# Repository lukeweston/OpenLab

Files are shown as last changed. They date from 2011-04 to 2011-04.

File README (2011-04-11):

Motherboard:

Because this board has a lot of hardware packed relatively tightly onto it, because it includes a few relatively exotic ICs which only exist as SMDs, and because of the size
restrictions of the Light version of Eagle, this board is designed almost entirely around surface-mount components.

Output Daughterboard:

This board contains the transistors for the open-collector transistor outputs (three of them), plus the amplifier and filter circuit for the analog waveform generator
output.

Because this board does not contain any particularly specialised ICs, and it does not require so many components packed on with such a high density, through-hole components
are used. Some people prefer through-hole components, and using through-hole components on this board means that it is more familar to construct for people who are not used
to working with surface mount components, and this means that this project includes both surface-mount components (on the motherboard), and through-hole components on this
daughterboard.

Pushbutton keypad board:

The pushbutton keypad is on its own separate small PCB. This makes it much easier to wire up the switches, compared to wiring up individual buttons manually.
This simple board includes the six pushbuttons and a string of resistors, and it is designed to be connected to a single analog input on the AVR and the button states
read by reading the analog voltage.

This is a very simple board which could easily be constructed by anyone, it is single sided, and the PCB is so simple that it could probably be fabricated at home.
It's probably quite valuable as a general pushbutton interface board for general Arduino activities outside the context of the ArduinoLab project, and this board probably
has wider appeal for these reasons.

I have written up the BOM for this board in a more verbose format, translating the Eagle-generated BOM into Digi-Key and element14 part numbers, so you can easily go shopping
for components. I have not yet been through this for the other boards.

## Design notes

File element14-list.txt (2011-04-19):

Element 14

(5+1) 6 x MCP73831 IC, SOT23-5 package				1332158		$1.44	
(5+1) 6 x LD1117S33 voltage regulator, SOT-223 package		1467779		$1.18
(5+1) 6 x 4053 IC, SOIC package					1014064		$0.847
(5x2+1) 11 x 4094 IC, SOIC package				1201297		$0.747

(5x3+2) 17 x MMBT2222 NPN transistor, SOT-23 package		1467896		$0.13
(5+1)    6 x FDS9431A P-channel MOSFET				1467989		$1.10
(5x6+2) 32 x green LED, SMD 0805				1686075		$0.158
(5x4+2) 22 x 5.6 V Zener diode, SOD-223				1757862		$0.06		

(5+1) 6 x 1 R, 1 W, SMD 2512 package				9235833		$0.097	
(5+1) 6 x 10 k SMD trimpot					46M2527		$0.134
(5x2) 10 x 10 k pot, standard panel-mounting 24 mm.		32M9482		$1.71

(5x10+5) 55 x 100 nF capacitor, SMD 0805			1759265		$0.018		
(5x2+2) 12 x 22 pF ceramic capacitor, SMD 0805			06R4053		$0.016

5 x 47 uF 10 V tantalum capacitor, SMD 'C' package		1754064		$0.795		
5 x 10 uF 10 V tantalum capacitor, SMD 'C' package		9753907		$0.832		
5 x 4700 uF 10 V electrolytic, through-hole, 5.08 mm pitch	9692754		$1.67

5 x 0.1" jumper shunt						1097975		$0.557		
(5x2) 10 x AA battery clips, PCB mounting.			908733		$6.09		
5 x 16 MHz crystal, HC-49S					1611734		$0.88	
(5+1) 6 x USB mini 'B' connector, SMD				1125348		$2.32		
5 x 2x3 pin header, for ICSP					1248132		$0.705		

(5x3) 15 x Green LED, through-hole, 3 mm			1461623		$0.14		
(5x3) 15 x 1N5819 diode, through-hole package			1017589		$0.173			
(5x3) 15 x 1N4004 diode, through-hole package			9109595		$0.034

5 x 1 nF ceramic capacitor, 0.1" lead pitch			1694095		$0.10		
(5x4) 20 x 100 nF ceramic capacitor, 0.1" lead pitch		1457658		$0.141

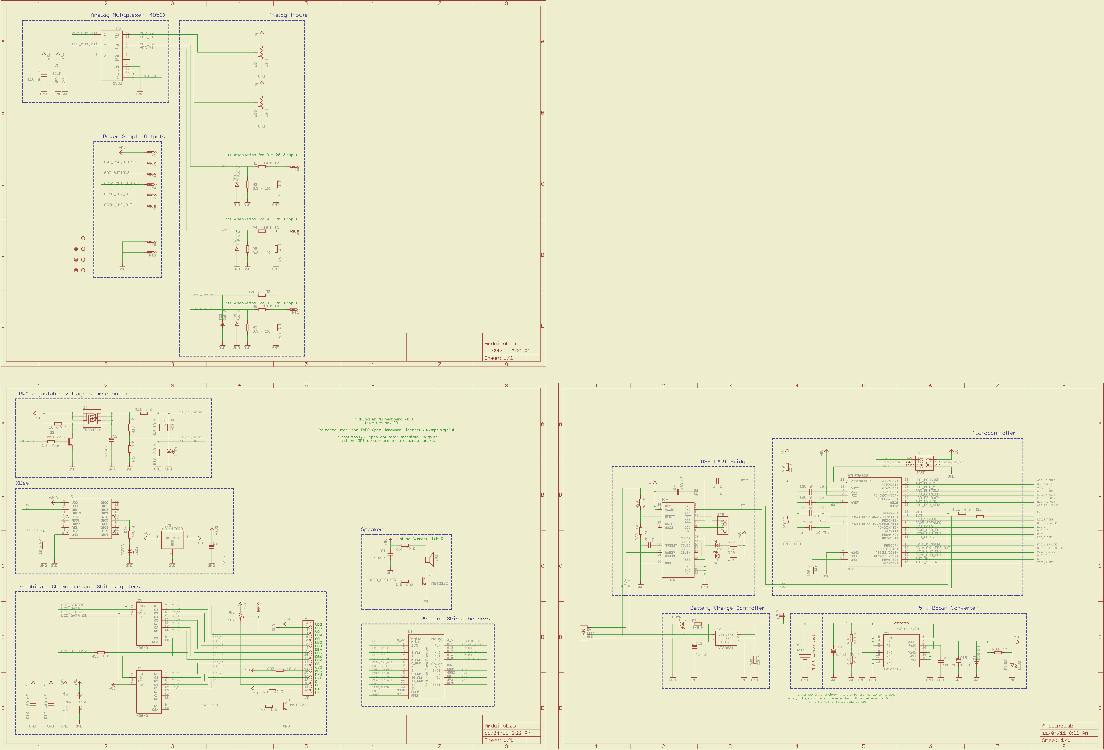
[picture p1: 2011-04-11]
motherboard/images/ArduinoLabMotherboardSchematic.png

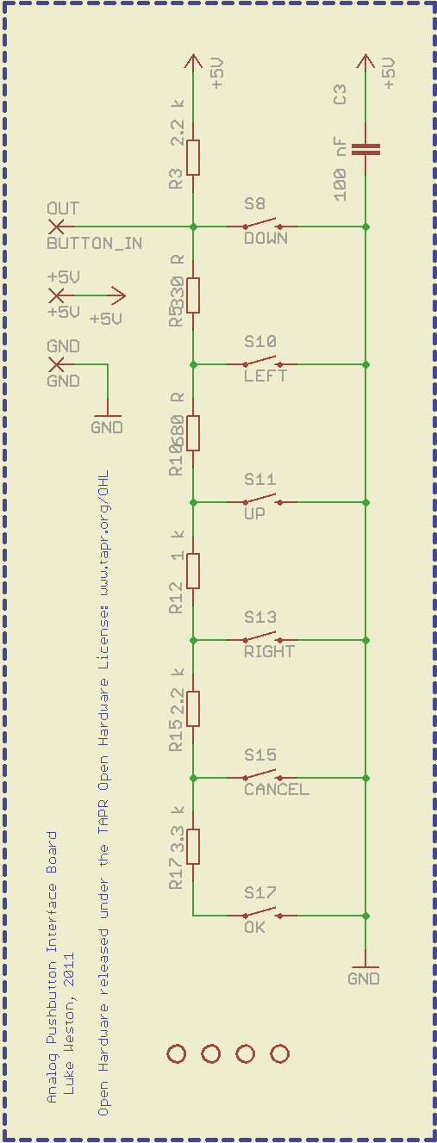
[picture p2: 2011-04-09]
buttons/images/PushbuttonsSchematic.png

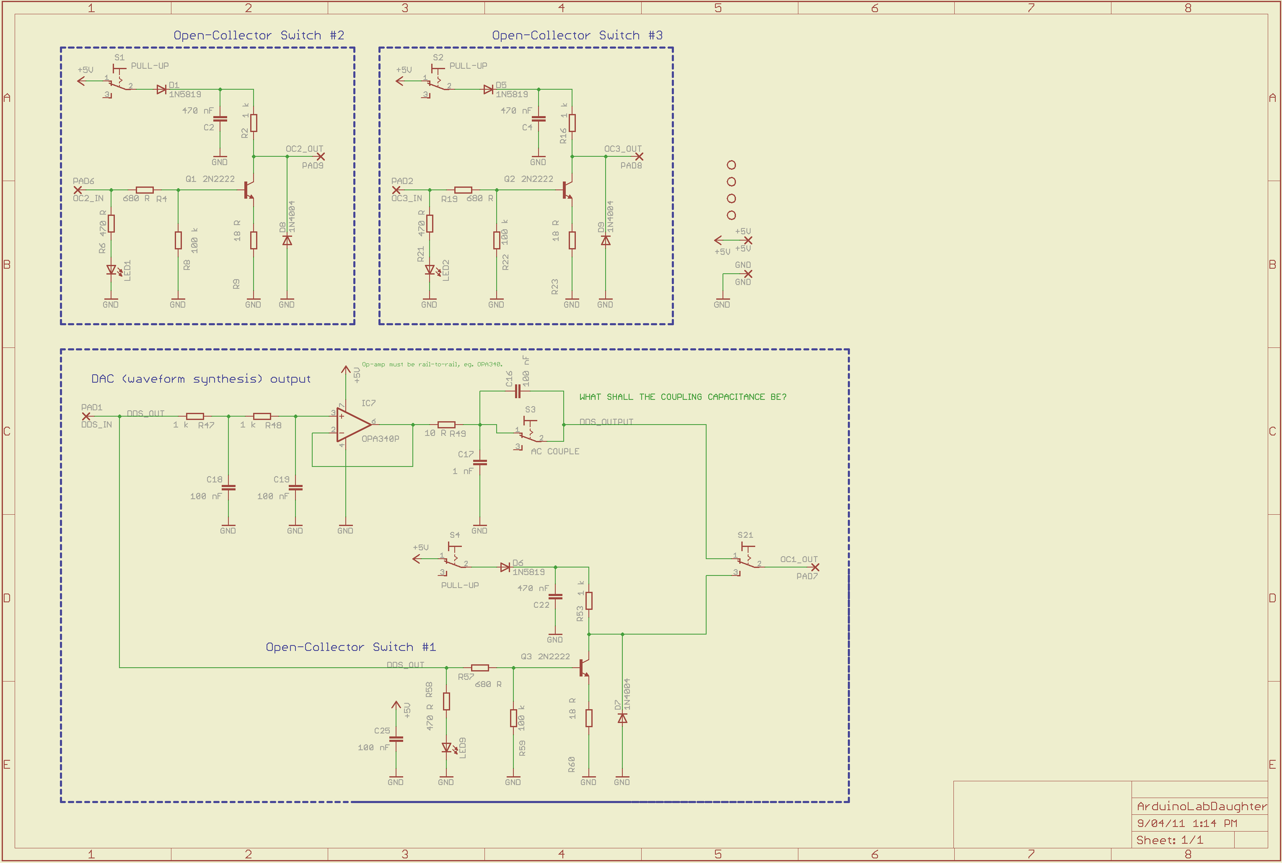
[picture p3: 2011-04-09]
daughterboard/images/ArduinoLabDaughterboardSchematic.png

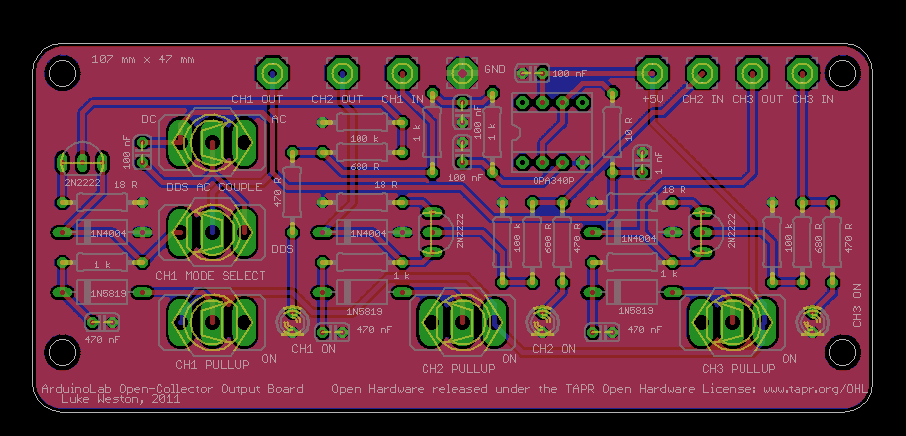
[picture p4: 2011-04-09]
daughterboard/images/ArduinoLabDaughterboardPCB.png

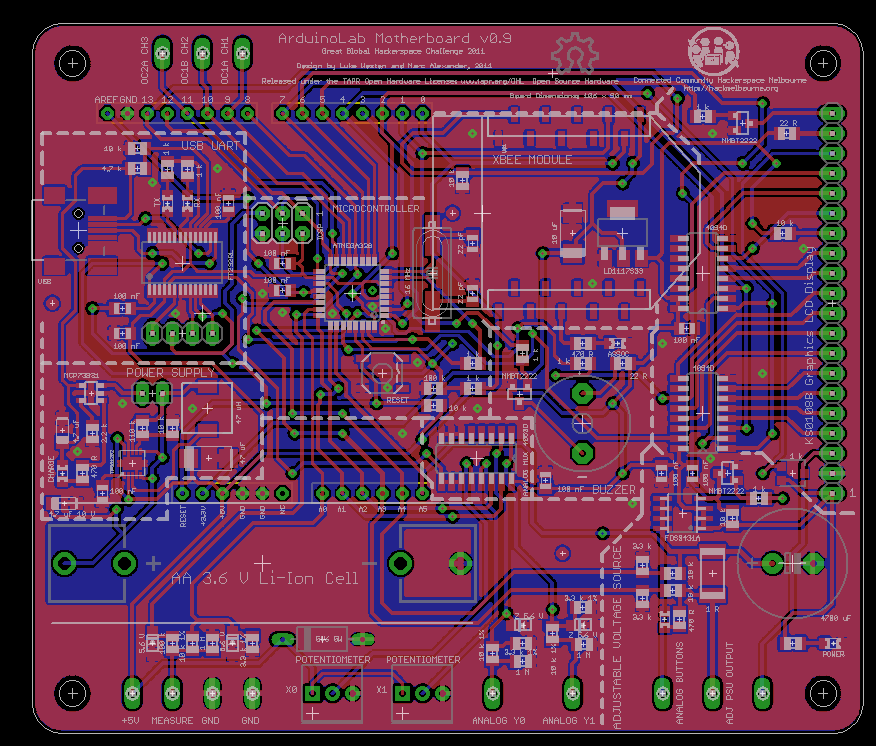
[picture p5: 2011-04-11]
motherboard/images/ArduinoLabMotherboardPCB.png

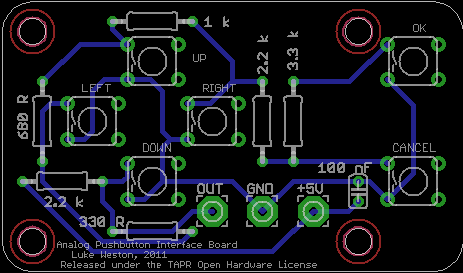
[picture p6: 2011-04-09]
buttons/images/PushbuttonPCB.png

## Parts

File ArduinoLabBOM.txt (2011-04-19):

Element 14
----------

Motherboards:
-------------
								
(5+1) 6 x MCP73831 IC, SOT23-5 package				1332158		$1.44	
(5+1) 6 x LD1117S33 voltage regulator, SOT-223 package		1467779		$1.18
(5+1) 6 x 4053 IC, SOIC package					1014064		$0.847
(5x2+1) 11 x 4094 IC, SOIC package				1201297		$0.747

(5x3+2) 17 x MMBT2222 NPN transistor, SOT-23 package		1467896		$0.13
(5+1)    6 x FDS9431A P-channel MOSFET				1467989		$1.10
(5x6+2) 32 x green LED, SMD 0805				1686075		$0.158
(5x4+2) 22 x 5.6 V Zener diode, SOD-223				1757862		$0.06		

(5+1) 6 x 1 R, 1 W, SMD 2512 package				9235833		$0.097	
(5+1) 6 x 10 k SMD trimpot					46M2527		$0.134
(5x2) 10 x 10 k pot, standard panel-mounting 24 mm.		32M9482		$1.71

(5x10+5) 55 x 100 nF capacitor, SMD 0805			1759265		$0.018		
(5x2+2) 12 x 22 pF ceramic capacitor, SMD 0805			06R4053		$0.016

5 x 47 uF 10 V tantalum capacitor, SMD 'C' package		1754064		$0.795		
5 x 10 uF 10 V tantalum capacitor, SMD 'C' package		9753907		$0.832		
5 x 4700 uF 10 V electrolytic, through-hole, 5.08 mm pitch	9692754		$1.67

5 x 0.1" jumper shunt						1097975		$0.557		
(5x2) 10 x AA battery clips, PCB mounting.			908733		$6.09		
5 x 16 MHz crystal, HC-49S					1611734		$0.88	
(5+1) 6 x USB mini 'B' connector, SMD				1125348		$2.32		
5 x 2x3 pin header, for ICSP					1248132		$0.705		

Output Daughterboards and Pushbutton Keypads:
----------------------------------------------

(5x3) 15 x Green LED, through-hole, 3 mm			1461623		$0.14		
(5x3) 15 x 1N5819 diode, through-hole package			1017589		$0.173			
(5x3) 15 x 1N4004 diode, through-hole package			9109595		$0.034

5 x 1 nF ceramic capacitor, 0.1" lead pitch			1694095		$0.10		
(5x4) 20 x 100 nF ceramic capacitor, 0.1" lead pitch		1457658		$0.141

Digi-Key
--------

Motherboards:
-------------
												
(5+1) 6 x TPS61202 IC, QFN-10 package								296-24865-1-ND		$3.30	
5 x 5.6 V 5 W Zener diode, through-hole								1N5339BGOS-ND		$0.44
(5x2) 10 x 4.7 uF 10 V tantalum capacitor, SMD 'A' package					478-3869-1-ND		$0.38
5 x piezo speaker										445-2525-1-ND		$0.39
(5+1) 6 x 4.7 uH 1.2 A inductor									495-2674-1-ND		$1.61
(5+1) 6 x SMD momentary tactile pushbutton							CKN9104CT-ND		$0.96
(5x2) 10 x 8-pin female 0.1" headers								S7006-ND		$0.75
(5x2)10 x 6-pin female 0.1" headers								S7004-ND		$0.59
(5x2) 10 x 10-pin 2 mm XBee headers								S5751-10-ND		$1.14
5 x 20-pin 0.1" female header, for LCD								S7018-ND		$1.56
(5x0.5) 3 x 40-pin 0.1" pin header for LCD cable						A26509-40-ND		$1.60	

SMD 0805 Resistors:
(5x9) 45 x 1 k											RMCF0805JT1K00CT-ND	$0.03
(5x3) 15 x 1 M											RMCF0805JT1M00CT-ND	$0.03
5 x 4.7 k											RMCF0805JT4K70CT-ND	$0.03
5 x 2.2 k											RMCF0805JT2K20CT-ND	$0.03
(5x2) 10 x 100 k											RMCF0805JT100KCT-ND	$0.03
(5x3) 15 x 470 R											RMCF0805JT470RCT-ND	$0.03
(5x2) 10 x 22 R											RMCF0805JT22R0CT-ND	$0.03

(5+5) 10 x 110 k, SMD 0805										P110KACT-ND		$0.04				
(5x5+5) 30 x 3.3 k, 1%, SMD 0805									RMCF0805FT3K30CT-ND	$0.04	
(11x5+5) 60 x 10 k, 1%, SMD 0805										RMCF0805FT10K0CT-ND	$0.04	

Output Daughterboards and Pushbutton Keypads:
----------------------------------------------

5 x OPA340P op-amp, DIP package									OPA340PA-ND	$2.48
(5x3) 15 x 2N2222 bipolar transistor, TO-92 through-hole						P2N2222AGOS-ND	$0.53
(5x3) 15 x 470 nF ceramic capacitor, 0.1" lead pitch							478-4858-ND	$0.36
(5x6) 30 x Momentary push-button switch, through-hole							450-1650-ND	$0.09
(5x3) 15 x 18 R resistor, 0.5 W									18H-ND		$0.062

Resistors: (all 0.4" through-hole, 0.25 W 1% or 5% unless specified.)
---------------------------------------------------------------------

(5x6) 30 x 1 k											1.0KQBK-ND	$0.07	
(5x4) 20 x 680 R											680QBK-ND	$0.07
(5x3) 15 x 470 R											470QBK-ND	$0.07	
(5x3) 15 x 100 k											100KQBK-ND	$0.07
5 x 10 R											10QBK-ND	$0.07
(5x2) 10 x 2.2 k											2.2KQBK-ND	$0.07	
5 x 330 R											330QBK-ND	$0.07
5 x 3.3 k											3.3KQBK-ND	$0.07

Other Stuff: LCD displays. FT232RL ICs. Toggle switches. PCB pins. Binding posts. Boxes. Batteries. AVR microcontrollers.
150 x Jaycar HP1250 PCB pins (used on daughterboards too)

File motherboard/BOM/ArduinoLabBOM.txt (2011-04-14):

ICs
----
								e14 SKU		e14 price	Digi-key SKU		Digikey price (USD)
												
1 x ATmega328 IC, TQFP-32 package				1715486		$9.80		ATMEGA328-AU-ND		$3.83
1 x FT232RL IC							114603		$7.94		768-1007-1-ND		$4.50
1 x TPS61202 IC, QFN-10 package					1564953		$6.20		296-24865-1-ND		$3.30	
1 x MCP73831 IC, SOT23-5 package				1332158		$1.44		MCP73831T-2ACI/OTCT-ND	$0.68	
1 x LD1117S33 voltage regulator, SOT-223 package		1467779		$1.18		497-1241-1-ND		$0.74
1 x 4053 IC, SOIC package					1014064		$0.847		296-14274-1-ND		$0.51
2 x 4094 IC, SOIC package					1201297		$0.747		296-27189-1-ND		$0.56

* Don't need to purchase ATmega328s and FT232RLs as they're coming from Jon's assembly people.

1 x graphics LCD display (don't need to order these, Marc is already getting them.)
`
Discrete Semiconductors
-----------------------

3 x MMBT2222 NPN transistor, SOT-23 package			1467896		$0.13		MMBT2222A-FDICT-ND	$0.32
1 x FDS9431A P-channel MOSFET					1467989		$1.10		FDS9431ACT-ND		$0.69
6 x green LED, SMD 0805						1686075		$0.158		754-1094-1-ND		$0.20
4 x 5.6 V Zener diode, SOD-223					1757862		$0.06		MMSZ5232BS-FDICT-ND	$0.42
1 x 5.6 V 5 W Zener diode, through-hole				1383755		$3.93		1N5339BGOS-ND		$0.44

Resistors
---------

9 x 1 k								1811778		$0.044		RMCF0805JT1K00CT-ND	$0.03
3 x 1 M								1811781		$0.044		RMCF0805JT1M00CT-ND	$0.03
1 x 4.7 k							1811904		$0.044		RMCF0805JT4K70CT-ND	$0.03
1 x 110 k							1469864		$0.03		P110KACT-ND		$0.04				
1 x 2.2 k							1811840		$0.044		RMCF0805JT2K20CT-ND	$0.03
2 x 100 k							1811780		$0.044		RMCF0805JT100KCT-ND	$0.03
3 x 470 R							1811902		$0.044		RMCF0805JT470RCT-ND	$0.03
2 x 22 R							1099789		$0.023		RMCF0805JT22R0CT-ND	$0.03

(SMD 0805 package for all the above, 5% tolerance 0.25 W or 0.125 W is fine.)

5 x 3.3 k, 1%, SMD 0805						1469911		$0.03		RMCF0805FT3K30CT-ND	$0.04	
11 x 10 k, 1%, SMD 0805						1652909		$0.02		RMCF0805FT10K0CT-ND	$0.04	
1 x 1 R, 1 W, SMD 2512 package					9235833		$0.097		RMCF2512JT1R00CT-ND	$0.44
1 x 10 k SMD trimpot						46M2527		$0.134		TC33X-103ECT-ND		$0.25
2 x 10 k pot, standard panel-mounting 24 mm.			32M9482		$1.71		??			??

Capacitors
----------

10 x 100 nF capacitor, SMD 0805					1759265		$0.018		311-1361-1-ND		$0.028
2 x 22 pF ceramic capacitor, SMD 0805				06R4053		$0.016		709-1172-1-ND		$0.044

1 x 47 uF 10 V tantalum capacitor, SMD 'C' package		1754064		$0.795		478-3911-1-ND		$0.46
1 x 10 uF 10 V tantalum capacitor, SMD 'C' package		9753907		$0.832		478-1702-1-ND		$0.40
2 x 4.7 uF 10 V tantalum capacitor, SMD 'A' package		1672491		$1.29		478-3869-1-ND		$0.38
1 x 4700 uF 10 V electrolytic, through-hole, 5.08 mm pitch	9692754		$1.67		P5130-ND		$0.90

Other
-----

1 x piezo speaker						??		??		445-2525-1-ND		$0.39
1 x 4.7 uH 1.2 A inductor					1644482		$4.19		495-2674-1-ND		$1.61
1 x 16 MHz crystal, HC-49S					1611734		$0.88		535-10226-1-ND		$0.41
1 x AA 3.6 V lithium-ion cell					??		??		??			??
1 x SMD momentary tactile pushbutton				??		??		CKN9104CT-ND		$0.96
1 x USB mini 'B' connector, SMD					1125348		$2.32		H2959CT-ND		$1.18

18 x PC pins							??		??		??			??
1 x 2x3 pin header, for ICSP					1248132		$0.705		3M9459-ND		$0.26
2 x 8-pin female 0.1" headers					??		??		S7006-ND		$0.75
2 x 6-pin female 0.1" headers					??		??		S7004-ND		$0.59
2 x 10-pin 2 mm XBee headers					??		??		S5751-10-ND		$1.14
1 x 2-pin 0.1" pin header, for jumper				??		??		??			??
1 x 20-pin 0.1" female header, for LCD				??		??		S7018-ND		$1.56
0.5 x 40-pin 0.1" pin header for LCD cable			??		??		A26509-40-ND		$1.60	
1 x 0.1" jumper shunt						1097975		$0.557		3M9580-ND		$0.06
2 x AA battery clips, PCB mounting.				908733		$6.09		??			??

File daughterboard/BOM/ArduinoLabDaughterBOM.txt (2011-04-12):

Semiconductors:
									e14 SKU		e14 price (AUD)		Digikey SKU	Digikey price (USD)
1 x OPA340P op-amp, DIP package						1097413		$3.94			OPA340PA-ND	$2.48
3 x 2N2222 bipolar transistor, TO-92 through-hole			1611371		$0.843			P2N2222AGOS-ND	$0.53
3 x Green LED, through-hole, 3 mm					1461623		$0.14			160-1710-ND	$0.52
3 x 1N5819 diode, through-hole package					1017589		$0.173			1N5819-TPCT-ND	$0.42
3 x 1N4004 diode, through-hole package					9109595		$0.034			641-1311-1-ND	$0.25

Capacitors:

3 x 470 nF ceramic capacitor, 0.1" lead pitch				3323225		$0.738			478-4858-ND	$0.36
1 x 1 nF ceramic capacitor, 0.1" lead pitch				1694095		$0.10			478-5217-ND	$0.29
3 x 100 nF ceramic capacitor, 0.1" lead pitch				1457658		$0.141			478-3192-ND	$0.16
1 x bipolar electrolytic, 0.1" lead pitch, value to be determined.	??

Miscellaneous:

5 x SPDT toggle switch							??
8 x PCB pins								??

Resistors: (all 0.4" through-hole, 0.25 W 1% or 5% unless specified.)

5 x 1 k									9339051*	$0.097			1.0KQBK-ND**	$0.07	
3 x 680 R								9339655*	$0.097			680QBK-ND**	$0.07
3 x 470 R								9339531*	$0.097			470QBK-ND**	$0.07	
3 x 18 R, 0.5 W								9338535*	$0.021			18H-ND**	$0.062
3 x 100 k								9339078*	$0.097			100KQBK-ND**	$0.07
1 x 10 R								9339035*	$0.094			10QBK-ND**	$0.07

* Minimum purchase 50
** Minimum purchase 5

----------------------------------------------------------------------------------------------------------------------------------------------------------------------------

Partlist exported from /Users/Luke/Desktop/ArduinoLab/daughterboard/eagle/ArduinoLabDaughter.sch at 10/04/11 7:58 PM

Part Value     Device          Package       Description                         
+5V  +5V       WIREPAD3,81/1,3 3,81/1,3      Wire PAD connect wire on PCB        
C1   470 nF    C-EU025-024X044 C025-024X044  CAPACITOR, European symbol          
C2   470 nF    C-EU025-024X044 C025-024X044  CAPACITOR, European symbol          
C4   1 nF      C-EU025-024X044 C025-024X044  CAPACITOR, European symbol          
C5   100 nF    C-EU025-024X044 C025-024X044  CAPACITOR, European symbol          
C6   100 nF    C-EU025-024X044 C025-024X044  CAPACITOR, European symbol          
C7   470 nF    C-EU025-024X044 C025-024X044  CAPACITOR, European symbol          
C8   100 nF    C-EU025-024X044 C025-024X044  CAPACITOR, European symbol          
C9   BP        CPOL-EUE2.5-7   E2,5-7        POLARIZED CAPACITOR, European symbol
D1   1N5819    DIODE-D-10      D-10          DIODE                               
D2   1N5819    DIODE-D-10      D-10          DIODE                               
D3   1N4004    DIODE-D-10      D-10          DIODE                               
D4   1N4004    DIODE-D-10      D-10          DIODE                               
D5   1N5819    DIODE-D-10      D-10          DIODE                               
D6   1N4004    DIODE-D-10      D-10          DIODE                               
GND  GND       WIREPAD3,81/1,3 3,81/1,3      Wire PAD connect wire on PCB        
IC1  OPA340P   OPA340P         DIL08         Rail-to-Rail Operational Amplifiers 
JP1  STAND-OFF STAND-OFF       STAND-OFF     Stand Off                           
JP2  STAND-OFF STAND-OFF       STAND-OFF     Stand Off                           
JP3  STAND-OFF STAND-OFF       STAND-OFF     Stand Off                           
JP4  STAND-OFF STAND-OFF       STAND-OFF     Stand Off                           
LED1           LED3MM          LED3MM        LED                                 
LED2           LED3MM          LED3MM        LED                                 
LED3           LED3MM          LED3MM        LED                                 
PAD1 OC2_OUT   WIREPAD3,81/1,3 3,81/1,3      Wire PAD connect wire on PCB        
PAD2 OC3_OUT   WIREPAD3,81/1,3 3,81/1,3      Wire PAD connect wire on PCB        
PAD3 OC2_IN    WIREPAD3,81/1,3 3,81/1,3      Wire PAD connect wire on PCB        
PAD4 OC3_IN    WIREPAD3,81/1,3 3,81/1,3      Wire PAD connect wire on PCB        
PAD5 DDS_IN    WIREPAD3,81/1,3 3,81/1,3      Wire PAD connect wire on PCB        
PAD6 OC1_OUT   WIREPAD3,81/1,3 3,81/1,3      Wire PAD connect wire on PCB        
Q1   2N2222    2N2222          TO92-EBC-OVAL NPN TRANSISTOR                      
Q2   2N2222    2N2222          TO92-EBC-OVAL NPN TRANSISTOR                      
Q3   2N2222    2N2222          TO92-EBC-OVAL NPN TRANSISTOR                      
R1   1 k       R-EU_0207/10    0207/10       RESISTOR, European symbol           
R2   1 k       R-EU_0207/10    0207/10       RESISTOR, European symbol           
R3   680 R     R-EU_0207/10    0207/10       RESISTOR, European symbol           
R4   680 R     R-EU_0207/10    0207/10       RESISTOR, European symbol           
R5   470 R     R-EU_0207/10    0207/10       RESISTOR, European symbol           
R6   470 R     R-EU_0207/10    0207/10       RESISTOR, European symbol           
R7   100 k     R-EU_0207/10    0207/10       RESISTOR, European symbol           
R8   18 R      R-EU_0207/10    0207/10       RESISTOR, European symbol           
R9   100 k     R-EU_0207/10    0207/10       RESISTOR, European symbol           
R10  18 R      R-EU_0207/10    0207/10       RESISTOR, European symbol           
R11  1 k       R-EU_0207/10    0207/10       RESISTOR, European symbol           
R12  1 k       R-EU_0207/10    0207/10       RESISTOR, European symbol           
R13  10 R      R-EU_0207/10    0207/10       RESISTOR, European symbol           
R14  1 k       R-EU_0207/10    0207/10       RESISTOR, European symbol           
R15  680 R     R-EU_0207/10    0207/10       RESISTOR, European symbol           
R16  470 R     R-EU_0207/10    0207/10       RESISTOR, European symbol           
R17  100 k     R-EU_0207/10    0207/10       RESISTOR, European symbol           
R18  18 R      R-EU_0207/10    0207/10       RESISTOR, European symbol           
S1   PULL-UP   320-916         320-916       TOGGLE SWITCH                       
S2   PULL-UP   320-916         320-916       TOGGLE SWITCH                       
S3   AC COUPLE 320-916         320-916       TOGGLE SWITCH                       
S4   PULL-UP   320-916         320-916       TOGGLE SWITCH                       
S5             320-916         320-916       TOGGLE SWITCH

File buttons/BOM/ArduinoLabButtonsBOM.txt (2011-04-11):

Bill of materials for the pushbutton board.

I have "translated" this from the raw BOM exported from Eagle. Interpreting the BOM exported from the Eagle files and identifying appropriate components when you go shopping
can be a little bit tricky, it requires a little bit of interpretation.

Misc. components:
-----------------
									e14 SKU		Price (AUD)	Digikey SKU	Price (USD)	Jaycar		Price (AUD)
6 x Momentary push-button switch, through-hole.				1555985		$0.343		450-1650-ND	$0.09
1 x 100 nF ceramic capacitor, through-hole, 0.1" lead spacing.		1457658		$0.141		478-3192-ND	$0.16
3 x PCB pins																HP1250		$4.50/50

I can't find any PCB pins (the round kind with the flange, the same as Jaycar stocks) at either element14 or Digikey. Can anybody find them?

Resistors: All through-hole, 0.4" lead spacing, 0.25 W or 0.5 W, 5% or 1% tolerance.
-------------------------------------------------------------------------------------
		e14 SKU		Price (AUD)	Digikey SKU	Price (USD)
2 x 2.2 k	9339302*	$0.097		2.2KQBK-ND**	0.07
1 x 330 R	9339418*	$0.097		330QBK-ND**	0.07
1 x 680 R	9339655*	$0.097		680QBK-ND**	0.07
1 x 3.3 k	9339426*	$0.097		3.3KQBK-ND**	0.07
1 x 1 k		9339051*	$0.097		1.0KQBK-ND**	0.07

Prices are only for the smallest quantities, ignoring the lower high-volume pricing even though it might be appropriate for some things.

* 50 minimum
** 5 minimum

Below I have included the original text of the raw BOM file exported out of Eagle, so you can read it and compare it to what is above, for educational value.

--------------------------------------------------------------------------------------------------------------------------------------------------------------

Partlist exported from /Users/Luke/Desktop/ArduinoLab/buttons/eagle/ArduinoLabButtons.sch at 10/04/11 7:59 PM

Part Value     Device                Package      Description                 
+5V  +5V       WIREPAD3,81/1,3       3,81/1,3     Wire PAD connect wire on PCB
C1   100 nF    C-EU025-024X044       C025-024X044 CAPACITOR, European symbol  
GND  GND       WIREPAD3,81/1,3       3,81/1,3     Wire PAD connect wire on PCB
JP1  STAND-OFF STAND-OFF             STAND-OFF    Stand Off                   
JP2  STAND-OFF STAND-OFF             STAND-OFF    Stand Off                   
JP3  STAND-OFF STAND-OFF             STAND-OFF    Stand Off                   
JP4  STAND-OFF STAND-OFF             STAND-OFF    Stand Off                   
OUT  BUTTON_IN WIREPAD3,81/1,3       3,81/1,3     Wire PAD connect wire on PCB
R1   2.2 k     R-EU_0207/10          0207/10      RESISTOR, European symbol   
R2   330 R     R-EU_0207/10          0207/10      RESISTOR, European symbol   
R3   680 R     R-EU_0207/10          0207/10      RESISTOR, European symbol   
R4   1 k       R-EU_0207/10          0207/10      RESISTOR, European symbol   
R5   2.2 k     R-EU_0207/10          0207/10      RESISTOR, European symbol   
R6   3.3 k     R-EU_0207/10          0207/10      RESISTOR, European symbol   
S1   DOWN      SWITCH-MOMENTARY-2PTH TACTILE-PTH                              
S2   LEFT      SWITCH-MOMENTARY-2PTH TACTILE-PTH                              
S3   UP        SWITCH-MOMENTARY-2PTH TACTILE-PTH                              
S4   RIGHT     SWITCH-MOMENTARY-2PTH TACTILE-PTH                              
S5   CANCEL    SWITCH-MOMENTARY-2PTH TACTILE-PTH                              
S6   OK        SWITCH-MOMENTARY-2PTH TACTILE-PTH

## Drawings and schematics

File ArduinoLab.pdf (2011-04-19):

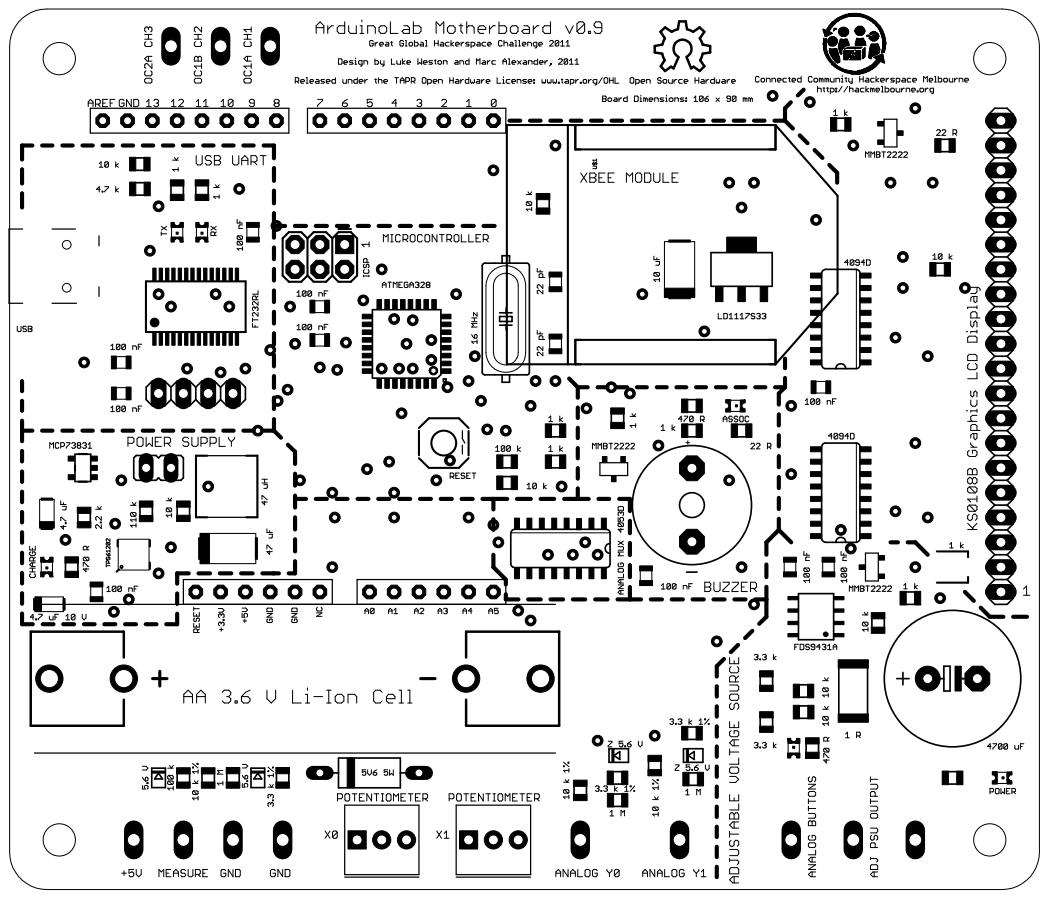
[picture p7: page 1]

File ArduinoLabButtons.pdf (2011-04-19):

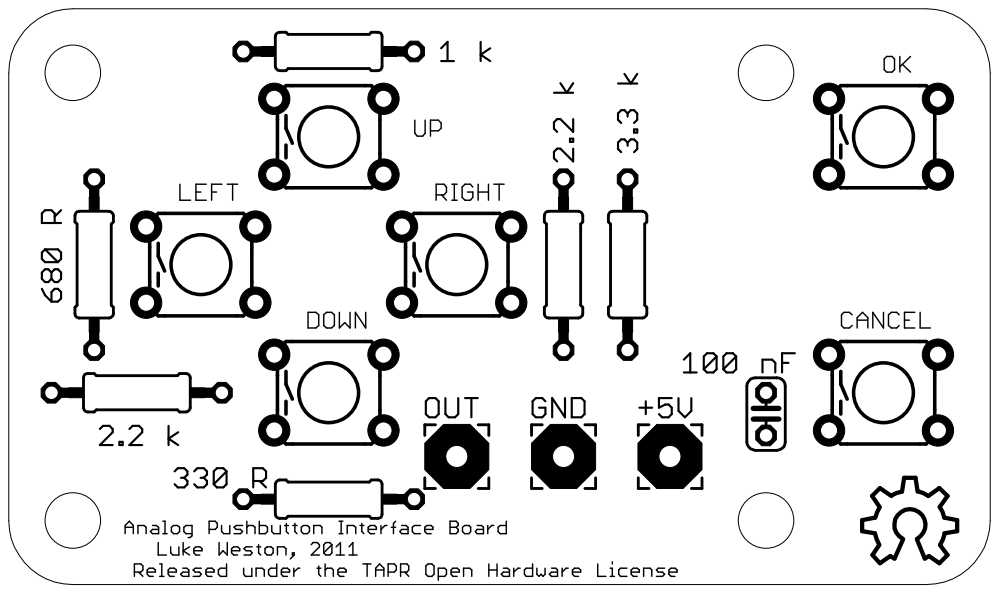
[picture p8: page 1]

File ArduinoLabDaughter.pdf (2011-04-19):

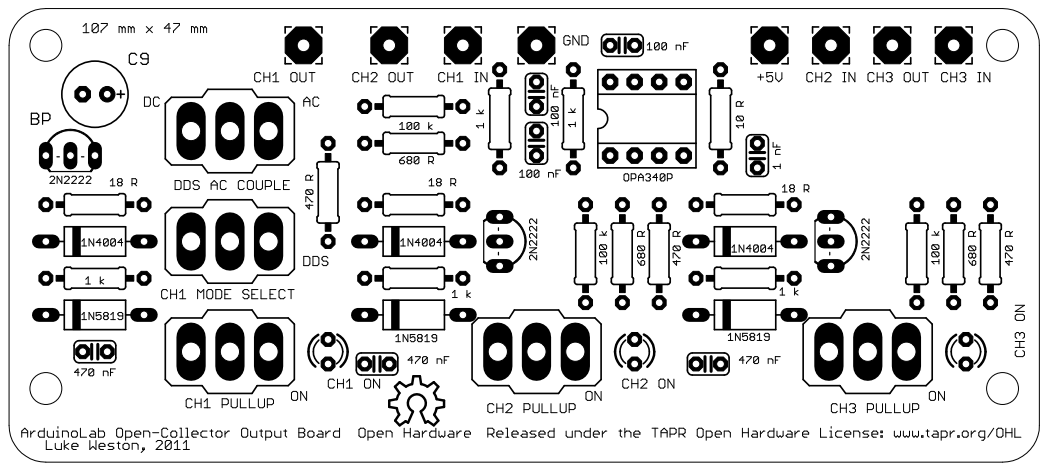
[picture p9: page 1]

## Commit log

2011-04-09 added round board corners on the two peripheral board
    [ArduinoLabButtons.brd, ArduinoLabDaughter.brd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]
2011-04-11 Merged Marc's changes to the motherboard back in.
    [ArduinoLab.brd, ArduinoLab.sch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]
2011-04-11 fixed USB connector
    [ArduinoLab.brd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]
2011-04-11 added pot labels
    [ArduinoLab.brd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]
2011-04-12 fixed Gerber files for button board
    [ArduinoLabButtons.brd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]
2011-04-14 finished BOM documentation
2011-04-19 added PDF images, at actual scale. Updated BOM stuff too.
    [ArduinoLabDaughter.brd]
